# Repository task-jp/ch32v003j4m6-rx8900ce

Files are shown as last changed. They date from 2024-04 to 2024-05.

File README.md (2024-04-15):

# Gathering CLOCK

Simple two LEDs clock that tells first 5mins in hours.

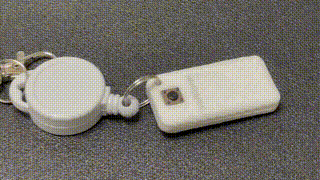
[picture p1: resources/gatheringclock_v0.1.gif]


## Features

|Min  |Green|Red  |
|-----|-----|-----|
|00-05|On | |
|05-10| |Blink|
|10-55| |On |
|55-60|Blink| |

* pushing a button for over 30 secs resets the clock

## Schematic and Layout

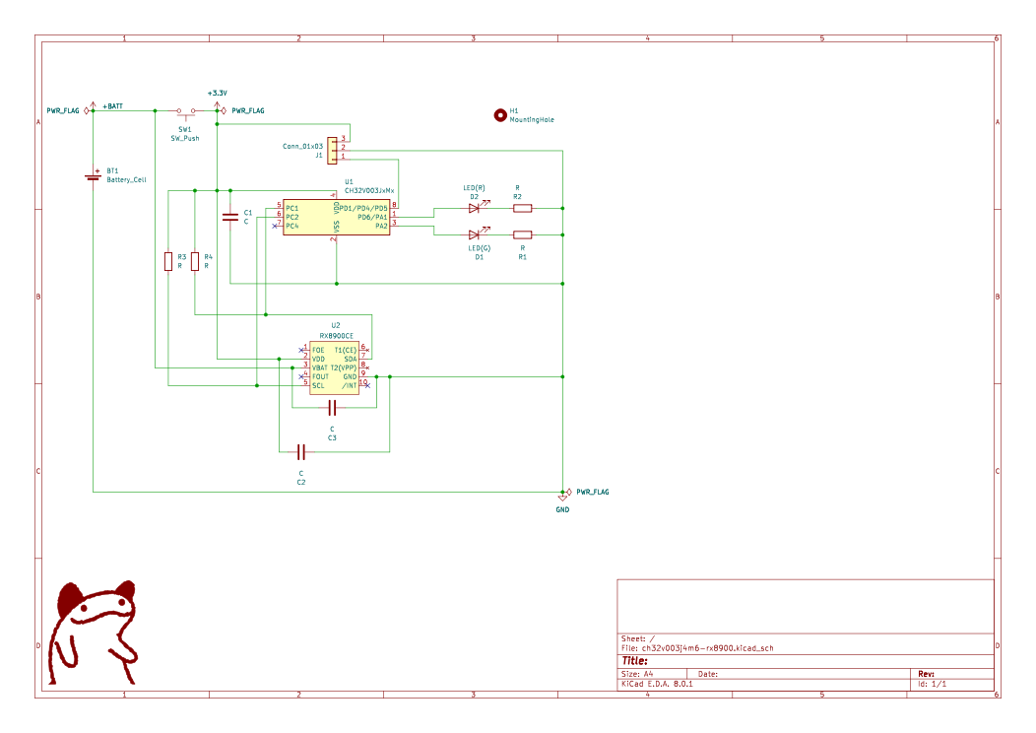
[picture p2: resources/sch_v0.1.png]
schmatic


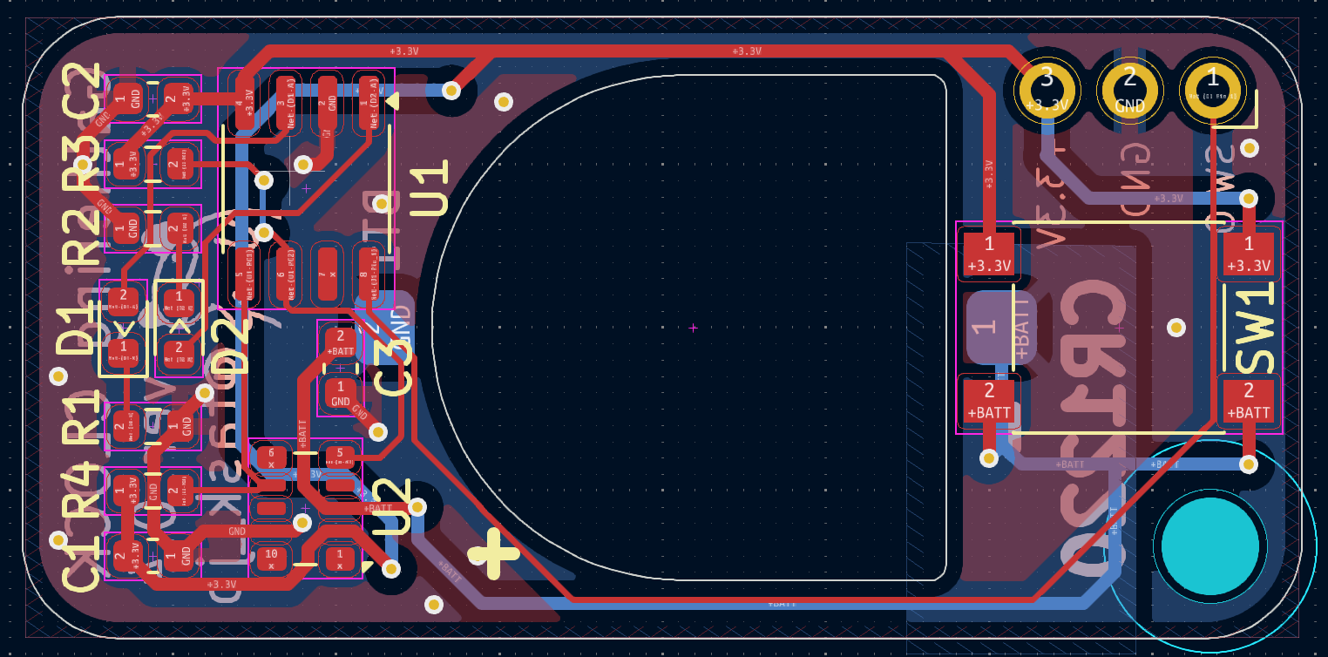
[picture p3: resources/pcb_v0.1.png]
layout


## Bill Of Materials

|Ref |Name |Qty|Description |Link |
|---|---|  -|---|---|
|U1 |CH32V003J4M6  |  1|Micro Controller|https://akizukidenshi.com/catalog/g/g118062/|
|U2 |RX8900CE |  1|RTC |https://akizukidenshi.com/catalog/g/g113320/|
|BT1 |Battery holder|  1|CR1220 |https://akizukidenshi.com/catalog/g/g109561/|
|D1 |LED |  1|Green |https://akizukidenshi.com/catalog/g/g106417/|
|D2 |LED |  1|Red |https://akizukidenshi.com/catalog/g/g103978/|
|C1,C2,C3|Capacitor |  3|0.1uF |https://akizukidenshi.com/catalog/g/g113374/|
|R1,R2 |Resistor 200  |  2|LED limit |https://akizukidenshi.com/catalog/g/g106201/|
|R3,R4 |Resistor 3K3  |  2|Pull up |https://akizukidenshi.com/catalog/g/g114661/|
|SW1 |Push Switch |  1| |https://akizukidenshi.com/catalog/g/g115969/|

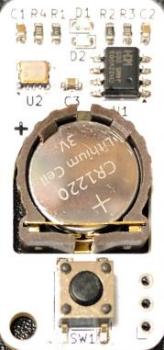
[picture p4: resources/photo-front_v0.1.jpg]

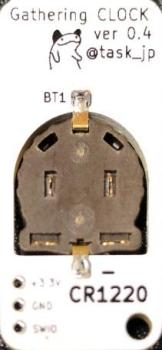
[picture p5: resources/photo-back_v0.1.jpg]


## Case

- [Fusion f3d file](./fusion/ch32v003j4m6-rx8900.f3d)
- STL
  - [Front](fusion/ch32v003j4m6-case-front.stl)
  - [Back](fusion/ch32v003j4m6-case-back.stl)

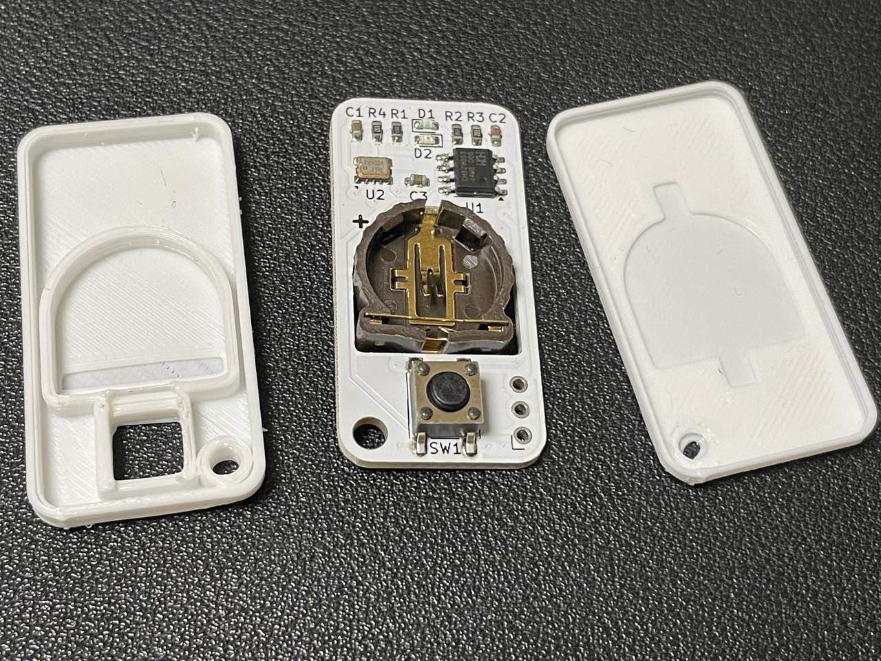
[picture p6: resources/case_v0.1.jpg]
case


## License
* MIT

## Author
* stasuku@gmail.com

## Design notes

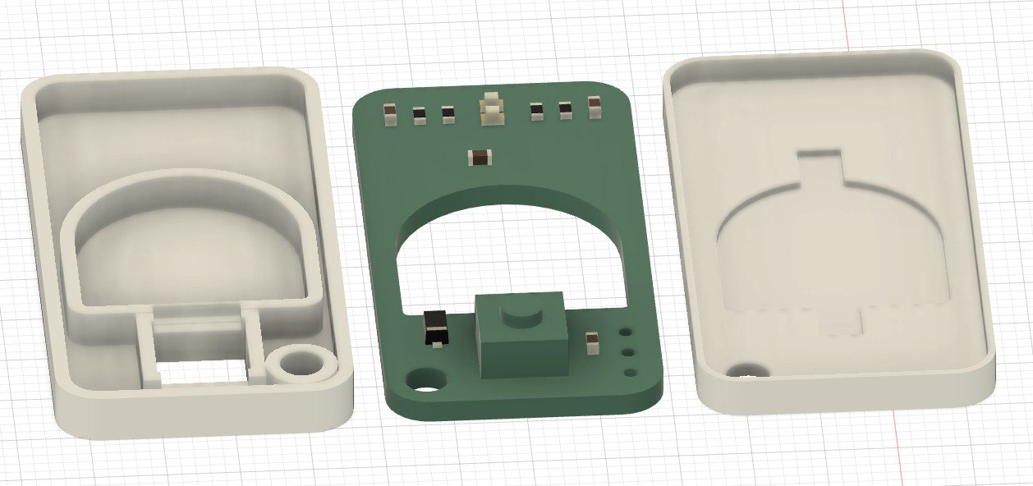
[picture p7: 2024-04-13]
resources/fusion_v0.1.png

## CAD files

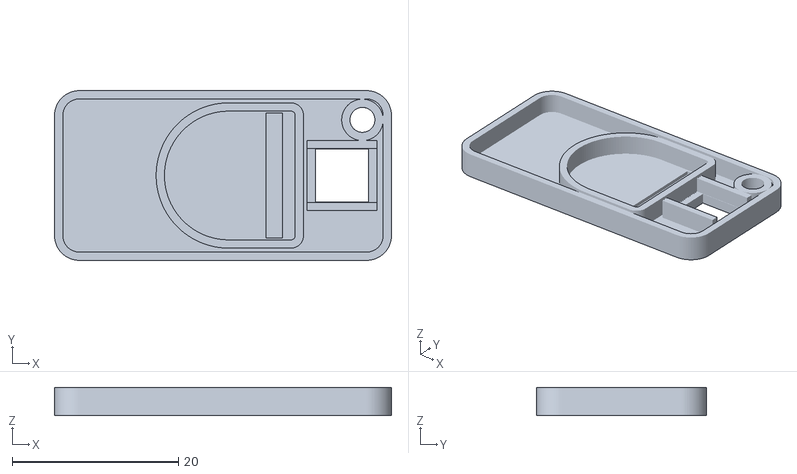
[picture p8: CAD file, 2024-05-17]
fusion/ch32v003j4m6-case-front.stl
40.6 x 20.4 x 3.40

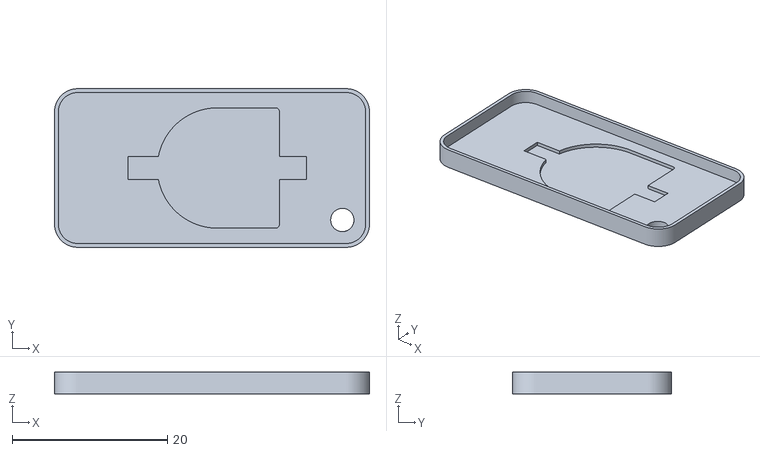
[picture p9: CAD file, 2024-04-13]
fusion/ch32v003j4m6-case-back.stl
40.6 x 20.5 x 2.80

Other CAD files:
fusion/ch32v003j4m6-rx8900.f3d

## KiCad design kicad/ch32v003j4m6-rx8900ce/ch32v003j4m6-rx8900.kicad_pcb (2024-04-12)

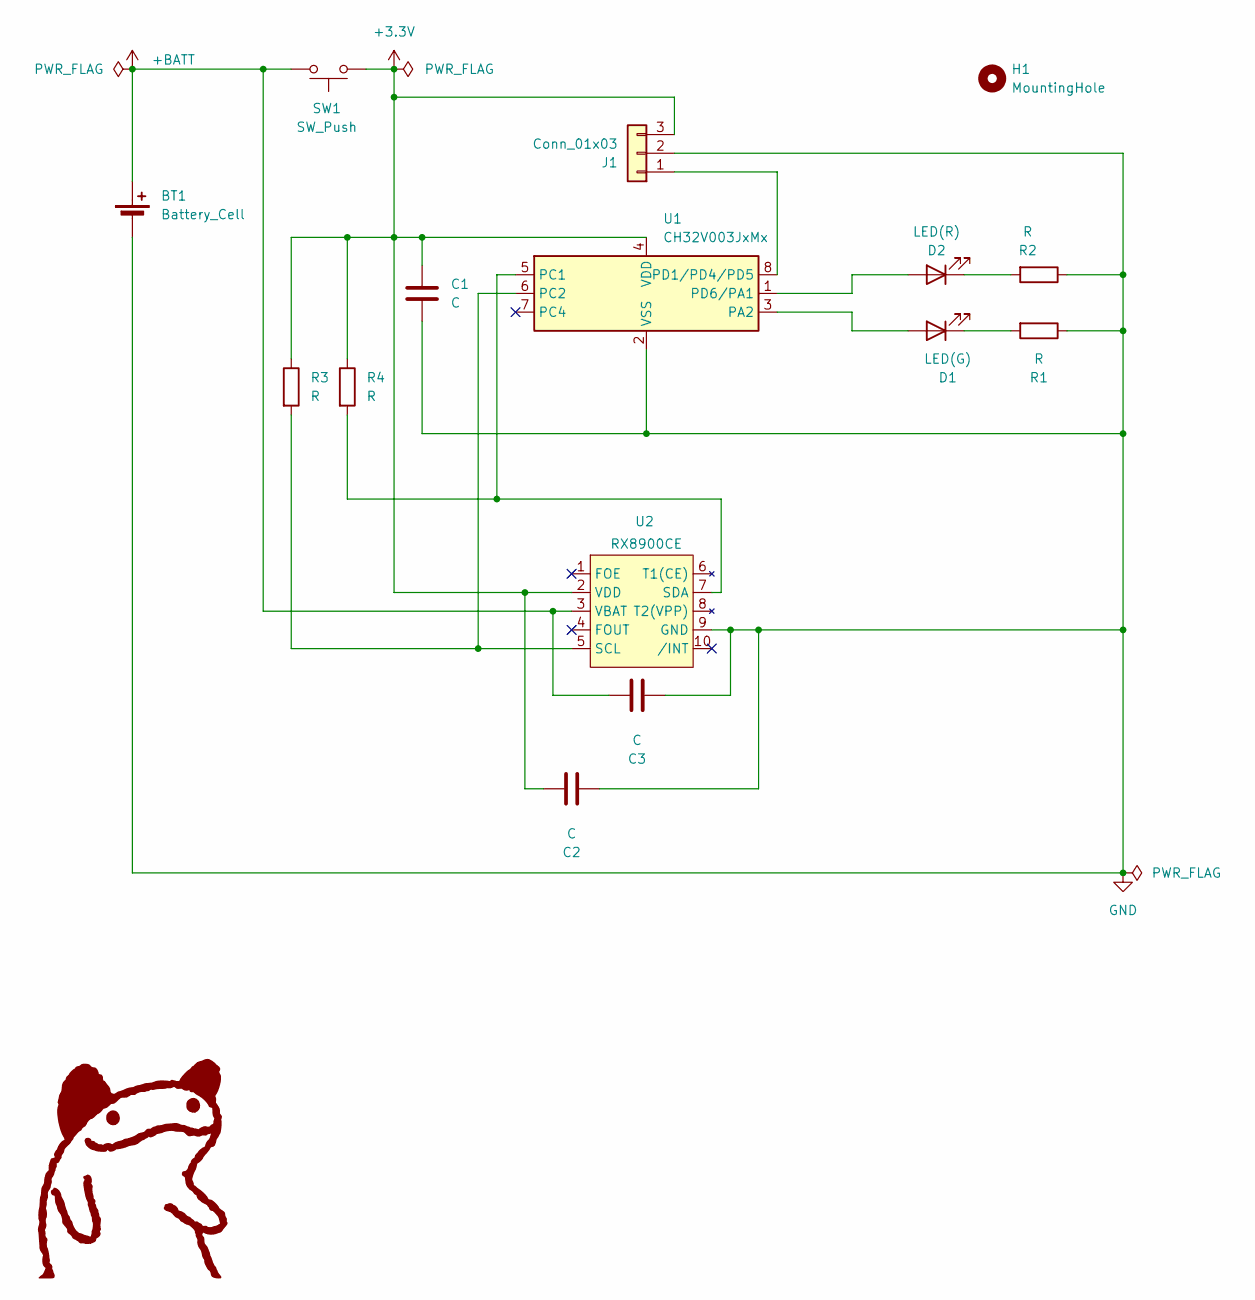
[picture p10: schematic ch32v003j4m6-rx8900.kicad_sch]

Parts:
BT1: Battery_Cell; CH291-1220LF
C1, C2, C3: C; C_0603_1608Metric
D1: LED(G); LED_0603_1608Metric
D2: LED(R); LED_0603_1608Metric
H1: MountingHole; MountingHole_3mm
J1: Conn_01x03; PinSocket_1x03_P2.54mm_Horizontal
R1, R2, R3, R4: R; R_0603_1608Metric
SW1: SW_Push; SW_Push_1P1T_NO_6x6mm_H9.5mm
U1: CH32V003JxMx; SOP-8_3.9x4.9mm_P1.27mm
U2: RX8900CE; EPSON_CE-USON-10_USON-10_3.2x2.5mm_P0.7mm

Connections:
+3.3V: C1.2, C2.2, J1.3, R3.1, R4.1, SW1.1, U1.4 (VDD), U2.2 (VDD)
+BATT: BT1.1 (+), C3.2, SW1.2, U2.3 (VBAT)
GND: BT1.2 (-), C1.1, C2.1, C3.1, J1.2, R1.1, R2.1, U1.2 (VSS), U2.9 (GND)
unnamed: D1.2 (A), U1.3 (PA2)
unnamed: D1.1 (K), R1.2
unnamed: D2.2 (A), U1.1 (PD6/PA1)
unnamed: D2.1 (K), R2.2
unnamed: J1.1, U1.8 (PD1/PD4/PD5)
unnamed: R4.2, U1.5 (PC1), U2.7 (SDA)
unnamed: R3.2, U1.6 (PC2), U2.5 (SCL)

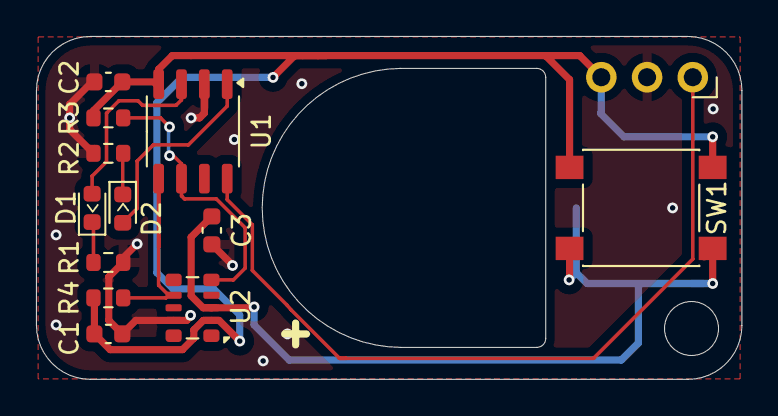
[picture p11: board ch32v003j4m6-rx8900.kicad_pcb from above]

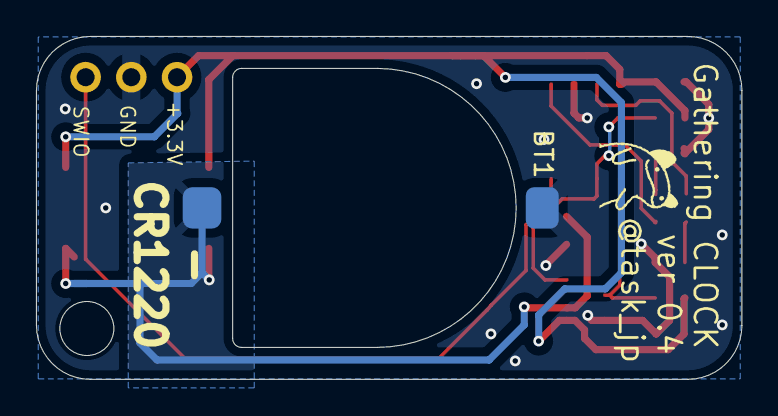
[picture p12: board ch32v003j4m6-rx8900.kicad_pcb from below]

Board: 2 copper layers, 39.2 x 19.0 mm, 15 parts (2 on the bottom side), 10 nets.

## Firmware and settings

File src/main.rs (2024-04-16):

#![no_std]
#![no_main]

use ch32v00x_hal as hal;
use ch32v_rt::entry;
use chrono::NaiveDateTime;
use hal::{i2c::*, pac::Peripherals, prelude::*};
use rx8900::Rx8900;
use fugit::HertzU32 as Hertz;
use embedded_hal::blocking::delay::DelayMs;
use hal::println;

#[panic_handler]
fn panic(info: &core::panic::PanicInfo) -> ! {
    println!("{}", info);
    loop {}
}

struct Ch32Delay {
    sysclock: Hertz,
}

impl Ch32Delay {
    fn new(sysclock: Hertz) -> Self {
        Self { sysclock }
    }
}

impl DelayMs<u32> for Ch32Delay
{
    fn delay_ms(&mut self, ms: u32) {
        let cycles = self.sysclock.raw() / 1000 * ms / 2;
        unsafe {
            qingke::riscv::asm::delay(cycles);
        }
    }
}

#[entry]
fn main() -> ! {
    #[cfg(feature = "sdi_print")]
    hal::debug::SDIPrint::enable();

    let pac = Peripherals::take().unwrap();

    let mut rcc = pac.RCC.constrain();
    let clocks = rcc.config.freeze();

    let gpioa = pac.GPIOA.split(&mut rcc);
    #[cfg(feature = "rtc")]
    let gpioc = pac.GPIOC.split(&mut rcc);
    let mut red = gpioa.pa1.into_push_pull_output();
    let mut green = gpioa.pa2.into_push_pull_output();
    #[cfg(feature = "rtc")]
    let sda = gpioc.pc1.into_alternate_open_drain();
    #[cfg(feature = "rtc")]
    let scl = gpioc.pc2.into_alternate_open_drain();
    #[cfg(feature = "rtc")]
    let i2c = I2c::i2c1(
        pac.I2C1,
        scl,
        sda,
        I2cConfig::fast_mode(),
        &mut rcc,
        &clocks,
    );

    let mut delay = Ch32Delay::new(clocks.sysclk());

    #[cfg(feature = "rtc")]
    let mut rx8900 = Rx8900::new(i2c);

    #[cfg(feature = "rtc")]
    match rx8900.voltage_low_flag() {
        Ok(true) => {
            #[cfg(feature = "sdi_print")]
            println!("Voltage low flag is set");
            rx8900.init().unwrap();
            delay.delay_ms(10u32);
            rx8900.set_datetime(NaiveDateTime::new(
                chrono::NaiveDate::from_ymd_opt(2024, 1, 1).unwrap(),
                chrono::NaiveTime::from_hms_opt(0, 0, 0).unwrap(),
            )).unwrap();
        },
        #[cfg(feature = "sdi_print")]
        Ok(false) => {
            println!("Voltage low flag is not set");
        },
        #[cfg(feature = "sdi_print")]
        Err(e) => {
            println!("Error occured: {:?}", e);
        },
        _ => {}
    }

    #[cfg(feature = "rtc")]
    let mut counter: usize = 0;
    #[cfg(feature = "rtc")]
    let mut last_second: u8 = core::u8::MAX;

    loop {
        #[cfg(feature = "rtc")]
        {
            let second = rx8900.sec().unwrap();
            if second == last_second {
                delay.delay_ms(10u32);
                continue;
            }

            if counter < 20 {
                counter += 1;
            } else if counter < 30 {
                counter += 1;
                green.set_low();
                red.set_high();
                delay.delay_ms(500);
                green.set_high();
                red.set_low();
                delay.delay_ms(400);
                continue;
            } else {
                green.set_high();
                red.set_high();
                rx8900.set_datetime(NaiveDateTime::new(
                    chrono::NaiveDate::from_ymd_opt(2024, 1, 1).unwrap(),
                    chrono::NaiveTime::from_hms_opt(0, 0, 0).unwrap(),
                )).unwrap();
                continue;
            }

            last_second = second;

            let minutes = rx8900.min().unwrap();
            #[cfg(feature = "sdi_print")]
            println!("{:02}:{:02}", minutes, second);

            match minutes {
                55..=59 => {
                    // 待ち合わせ時間直前5分間は緑を点滅
                    red.set_low();
                    green.set_high();
                    delay.delay_ms(500);
                    green.set_low();
                    delay.delay_ms(400);
                },
                0..=4 => {
                    // 5分間の待ち合わせ時間内は緑を点灯
                    green.set_high();
                    red.set_low();
                    delay.delay_ms(900);
                },
                5..=9 => {
                    // 待ち合わせ時間が過ぎたら5分間赤を点滅
                    red.set_high();
                    green.set_low();
                    delay.delay_ms(500);
                    red.set_low();
                    delay.delay_ms(400);
                },
                _ => {
                    // それ以外の場合は赤を点灯
                    green.set_low();
                    red.set_high();
                    delay.delay_ms(900);
                }
            }
        }

        #[cfg(not(feature = "rtc"))]
        {
            green.set_high();
            red.set_high();
            delay.delay_ms(500);
            green.set_low();
            delay.delay_ms(400);
        }
    }
}

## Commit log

2024-03-20 Add kicad files
    [ch32v003j4m6-rx8900.kicad_pcb, ch32v003j4m6-rx8900.kicad_sch]
2024-03-20 Keep reseting while button pressed over 60 secs
    [main.rs]
2024-03-20 Do not handle vlf != true when debug print is disabled
2024-03-21 Update kicad files
    [ch32v003j4m6-rx8900.kicad_pcb, ch32v003j4m6-rx8900.kicad_sch]
2024-04-12 Update pcb/sch
    [ch32v003j4m6-rx8900.kicad_pcb, ch32v003j4m6-rx8900.kicad_sch]
2024-04-12 Swap blink color befor/after the term
    [main.rs]
2024-04-12 Add case data
    [ch32v003j4m6-case-back.stl, ch32v003j4m6-case-front.stl, ch32v003j4m6-rx8900.f3d]
2024-04-13 Update case
    [ch32v003j4m6-case-back.stl, ch32v003j4m6-case-front.stl, ch32v003j4m6-rx8900.f3d]
2024-04-15 Fix suffix of case in README
2024-04-15 Update front cover
    [ch32v003j4m6-case-front.stl, ch32v003j4m6-rx8900.f3d]
2024-05-17 Update front case
    [ch32v003j4m6-case-front.stl]
